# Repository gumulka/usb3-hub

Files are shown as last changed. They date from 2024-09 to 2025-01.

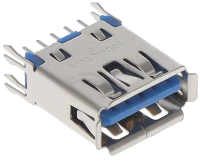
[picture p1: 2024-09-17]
kicad/images/GSB312137CHR.png

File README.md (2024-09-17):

# USB3 Hub

My very own USB3 Hub with these features:

* Power to all ports controllable via USB
* Power to all ports controllable via switch
* Current measurement on half the ports
* Current readout either via display or USB

## WIP

This is very much work in progress. I have not yet finished routing
and there is no software whatsoever for the PCB, but I'm working on it.

## Schematics

Can be found on the [here](https://gumulka.github.io/usb3-hub/usb3_hub_sch.pdf)

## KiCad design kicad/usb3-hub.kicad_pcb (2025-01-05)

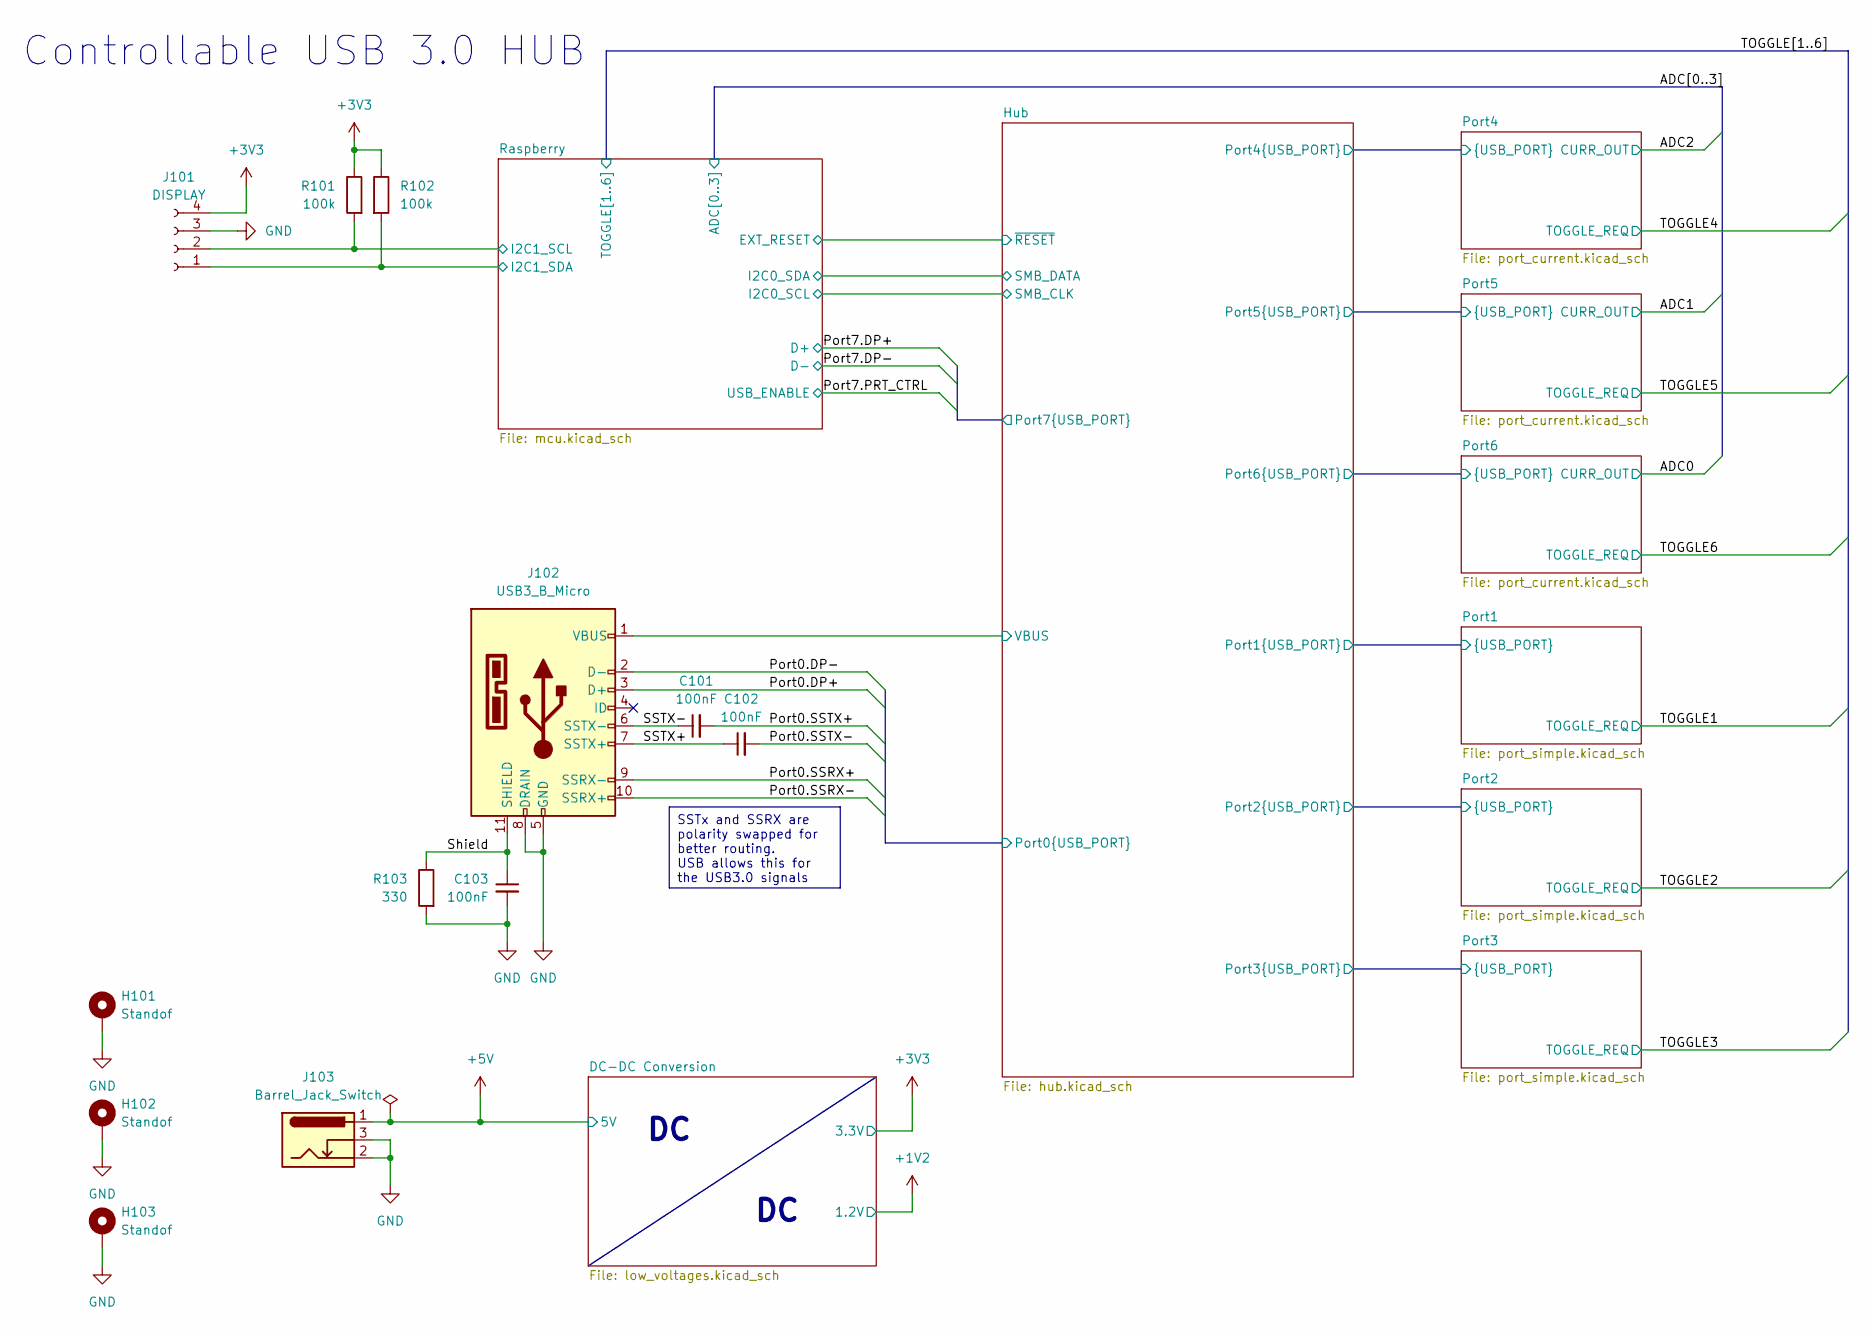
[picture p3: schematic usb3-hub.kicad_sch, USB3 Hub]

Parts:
C101, C102, C103: 100nF; C_0402_1005Metric
H101, H102, H103: Standof; MountingHole_3.2mm_M3_DIN965_Pad_TopOnly
J101: DISPLAY; PinSocket_1x04_P2.54mm_Vertical
J102: USB3_B_Micro; AMPHENOL_GSB443133HR
J103: Barrel_Jack_Switch; BarrelJack_Wuerth_6941xx301002; MPN 694106301002
R101, R102: 100k; R_0603_1608Metric
R103: 330; R_0603_1608Metric

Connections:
+3V3: J101.4, R101.1, R102.1; also elsewhere on the board
+5V: J103.1; also elsewhere on the board
/Hub/Port0.DP+: J102.3 (D+); also elsewhere on the board
/Hub/Port0.DP-: J102.2 (D-); also elsewhere on the board
/Hub/Port0.SSRX+: J102.9 (SSRX-); also elsewhere on the board
/Hub/Port0.SSRX-: J102.10 (SSRX+); also elsewhere on the board
/Hub/Port0.SSTX+: C101.2; also elsewhere on the board
/Hub/Port0.SSTX-: C102.2; also elsewhere on the board
/Hub/VBUS: J102.1 (VBUS); also elsewhere on the board
/Raspberry/I2C1_SCL: J101.2, R101.2; also elsewhere on the board
/Raspberry/I2C1_SDA: J101.1, R102.2; also elsewhere on the board
/SSTX+: C102.1, J102.7 (SSTX+)
/SSTX-: C101.1, J102.6 (SSTX-)
/Shield: C103.1, J102.11 (SHIELD), R103.1
GND: C103.2, H101.1, H102.1, H103.1, J101.3, J102.5 (GND), J102.8 (DRAIN), J103.2, J103.3, R103.2; also elsewhere on the board

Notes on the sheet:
SSTx and SSRX are polarity swapped for better routing. USB allows this for the USB3.0 signals
Controllable USB 3.0 HUB

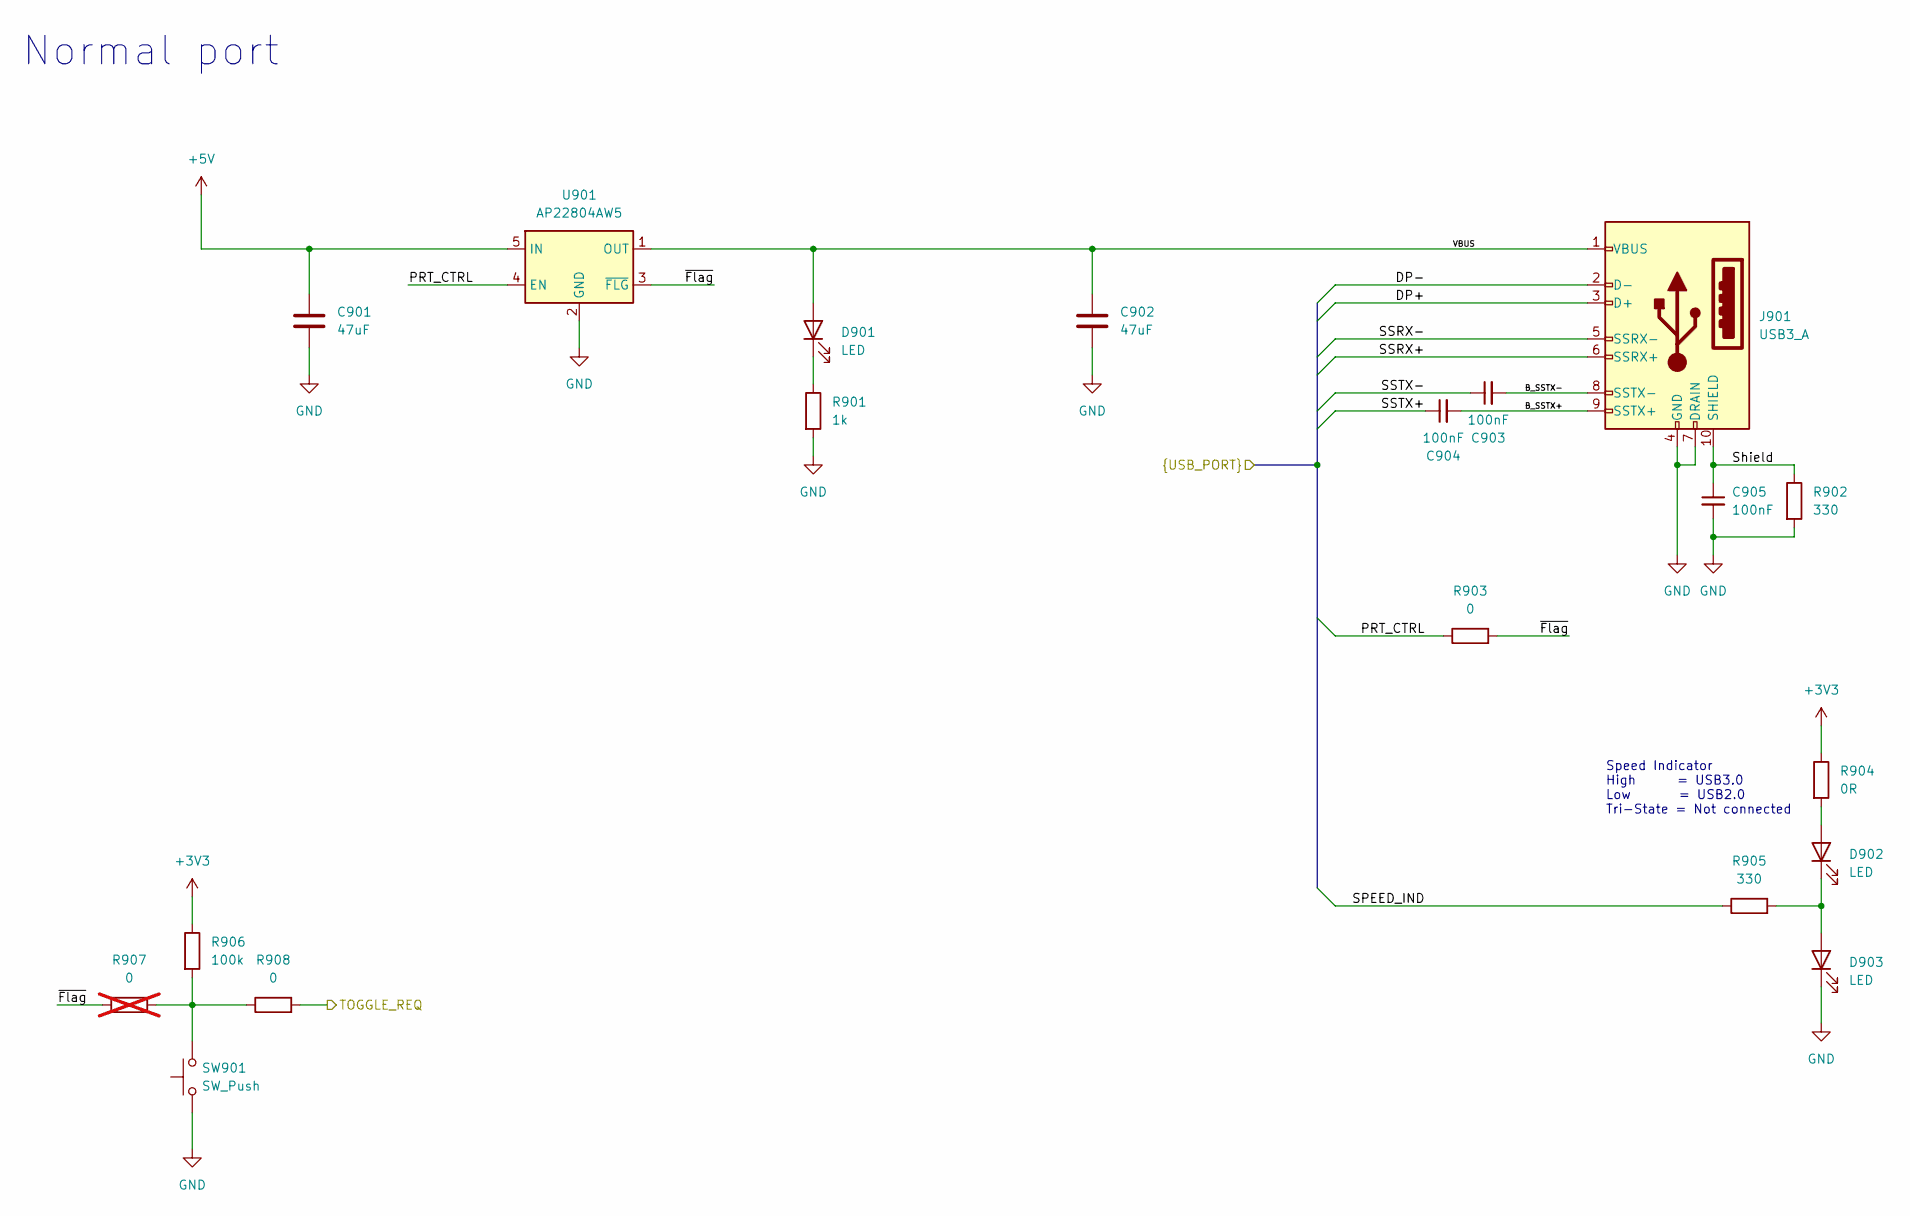
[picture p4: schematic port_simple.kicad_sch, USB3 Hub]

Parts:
C901, C902: 47uF; C_1210_3225Metric
C903, C904, C905: 100nF; C_0402_1005Metric
D901, D902, D903: LED; LED_0603_1608Metric
J901: USB3_A; AMPHENOL_GSB312137CHR
R901: 1k; R_0603_1608Metric
R902, R905: 330; R_0603_1608Metric
R903, R908: 0; R_0603_1608Metric
R904: 0R; R_0603_1608Metric
R906: 100k; R_0603_1608Metric
R907: 0; R_0603_1608Metric; not fitted
SW901: SW_Push; SW_SPST_TL3342
U901: AP22804AW5; SOT-23-5

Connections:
+3V3: R904.1, R906.1; also elsewhere on the board
+5V: C901.1, U901.5 (IN); also elsewhere on the board
/Hub/Port2.DP+: J901.3 (D+); also elsewhere on the board
/Hub/Port2.DP-: J901.2 (D-); also elsewhere on the board
/Hub/Port2.PRT_CTRL: R903.1, U901.4 (EN); also elsewhere on the board
/Hub/Port2.SPEED_IND: R905.1; also elsewhere on the board
/Hub/Port2.SSRX+: J901.6 (SSRX+); also elsewhere on the board
/Hub/Port2.SSRX-: J901.5 (SSRX-); also elsewhere on the board
/Hub/Port2.SSTX+: C904.1; also elsewhere on the board
/Hub/Port2.SSTX-: C903.1; also elsewhere on the board
/Port2/B_SSTX+: C904.2, J901.9 (SSTX+)
/Port2/B_SSTX-: C903.2, J901.8 (SSTX-)
/Port2/Shield: C905.1, J901.10 (SHIELD), R902.1
/Port2/VBUS: C902.1, D901.2 (A), J901.1 (VBUS), U901.1 (OUT)
/Port2/~Flag: R903.2, R907.1, U901.3 (~FLG)
/TOGGLE2: R908.2; also elsewhere on the board
GND: C901.2, C902.2, C905.2, D903.1 (K), J901.4 (GND), J901.7 (DRAIN), R901.2, R902.2, SW901.1, U901.2 (GND); also elsewhere on the board
unnamed: D901.1 (K), R901.1
unnamed: D902.2 (A), R904.2
unnamed: D902.1 (K), D903.2 (A), R905.2
unnamed: R906.2, R907.2, R908.1, SW901.2

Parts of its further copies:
C801, C802, C1001, C1002: 47uF; C_1210_3225Metric
C803, C804, C805, C1003, C1004, C1005: 100nF; C_0402_1005Metric
D801, D802, D803, D1001, D1002, D1003: LED; LED_0603_1608Metric
J801, J1001: USB3_A; AMPHENOL_GSB312137CHR
R801, R1001: 1k; R_0603_1608Metric
R802, R805, R1002, R1005: 330; R_0603_1608Metric
R803, R808, R1003, R1008: 0; R_0603_1608Metric
R804, R1004: 0R; R_0603_1608Metric
R806, R1006: 100k; R_0603_1608Metric
R807, R1007: 0; R_0603_1608Metric; not fitted
SW801, SW1001: SW_Push; SW_SPST_TL3342
U801, U1001: AP22804AW5; SOT-23-5

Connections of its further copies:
+3V3: R804.1, R806.1, R1004.1, R1006.1; also elsewhere on the board
+5V: C801.1, C1001.1, U801.5 (IN), U1001.5 (IN); also elsewhere on the board
/Hub/Port1.DP+: J801.3 (D+); also elsewhere on the board
/Hub/Port1.DP-: J801.2 (D-); also elsewhere on the board
/Hub/Port1.PRT_CTRL: R803.1, U801.4 (EN); also elsewhere on the board
/Hub/Port1.SPEED_IND: R805.1; also elsewhere on the board
/Hub/Port1.SSRX+: J801.6 (SSRX+); also elsewhere on the board
/Hub/Port1.SSRX-: J801.5 (SSRX-); also elsewhere on the board
/Hub/Port1.SSTX+: C804.1; also elsewhere on the board
/Hub/Port1.SSTX-: C803.1; also elsewhere on the board
/Hub/Port3.DP+: J1001.3 (D+); also elsewhere on the board
/Hub/Port3.DP-: J1001.2 (D-); also elsewhere on the board
/Hub/Port3.PRT_CTRL: R1003.1, U1001.4 (EN); also elsewhere on the board
/Hub/Port3.SPEED_IND: R1005.1; also elsewhere on the board
/Hub/Port3.SSRX+: J1001.6 (SSRX+); also elsewhere on the board
/Hub/Port3.SSRX-: J1001.5 (SSRX-); also elsewhere on the board
/Hub/Port3.SSTX+: C1004.1; also elsewhere on the board
/Hub/Port3.SSTX-: C1003.1; also elsewhere on the board
/Port1/B_SSTX+: C804.2, J801.9 (SSTX+)
/Port1/B_SSTX-: C803.2, J801.8 (SSTX-)
/Port1/Shield: C805.1, J801.10 (SHIELD), R802.1
/Port1/VBUS: C802.1, D801.2 (A), J801.1 (VBUS), U801.1 (OUT)
/Port1/~Flag: R803.2, R807.1, U801.3 (~FLG)
/Port3/B_SSTX+: C1004.2, J1001.9 (SSTX+)
/Port3/B_SSTX-: C1003.2, J1001.8 (SSTX-)
/Port3/Shield: C1005.1, J1001.10 (SHIELD), R1002.1
/Port3/VBUS: C1002.1, D1001.2 (A), J1001.1 (VBUS), U1001.1 (OUT)
/Port3/~Flag: R1003.2, R1007.1, U1001.3 (~FLG)
/TOGGLE1: R808.2; also elsewhere on the board
/TOGGLE3: R1008.2; also elsewhere on the board
GND: C801.2, C802.2, C805.2, C1001.2, C1002.2, C1005.2, D803.1 (K), D1003.1 (K), J801.4 (GND), J801.7 (DRAIN), J1001.4 (GND), J1001.7 (DRAIN), R801.2, R802.2, R1001.2, R1002.2, SW801.1, SW1001.1, U801.2 (GND), U1001.2 (GND); also elsewhere on the board
unnamed: D801.1 (K), R801.1
unnamed: D802.2 (A), R804.2
unnamed: D802.1 (K), D803.2 (A), R805.2
unnamed: D1001.1 (K), R1001.1
unnamed: D1002.2 (A), R1004.2
unnamed: D1002.1 (K), D1003.2 (A), R1005.2
unnamed: R806.2, R807.2, R808.1, SW801.2
unnamed: R1006.2, R1007.2, R1008.1, SW1001.2

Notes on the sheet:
Speed Indicator High = USB3.0 Low = USB2.0 Tri-State = Not connected
Normal port

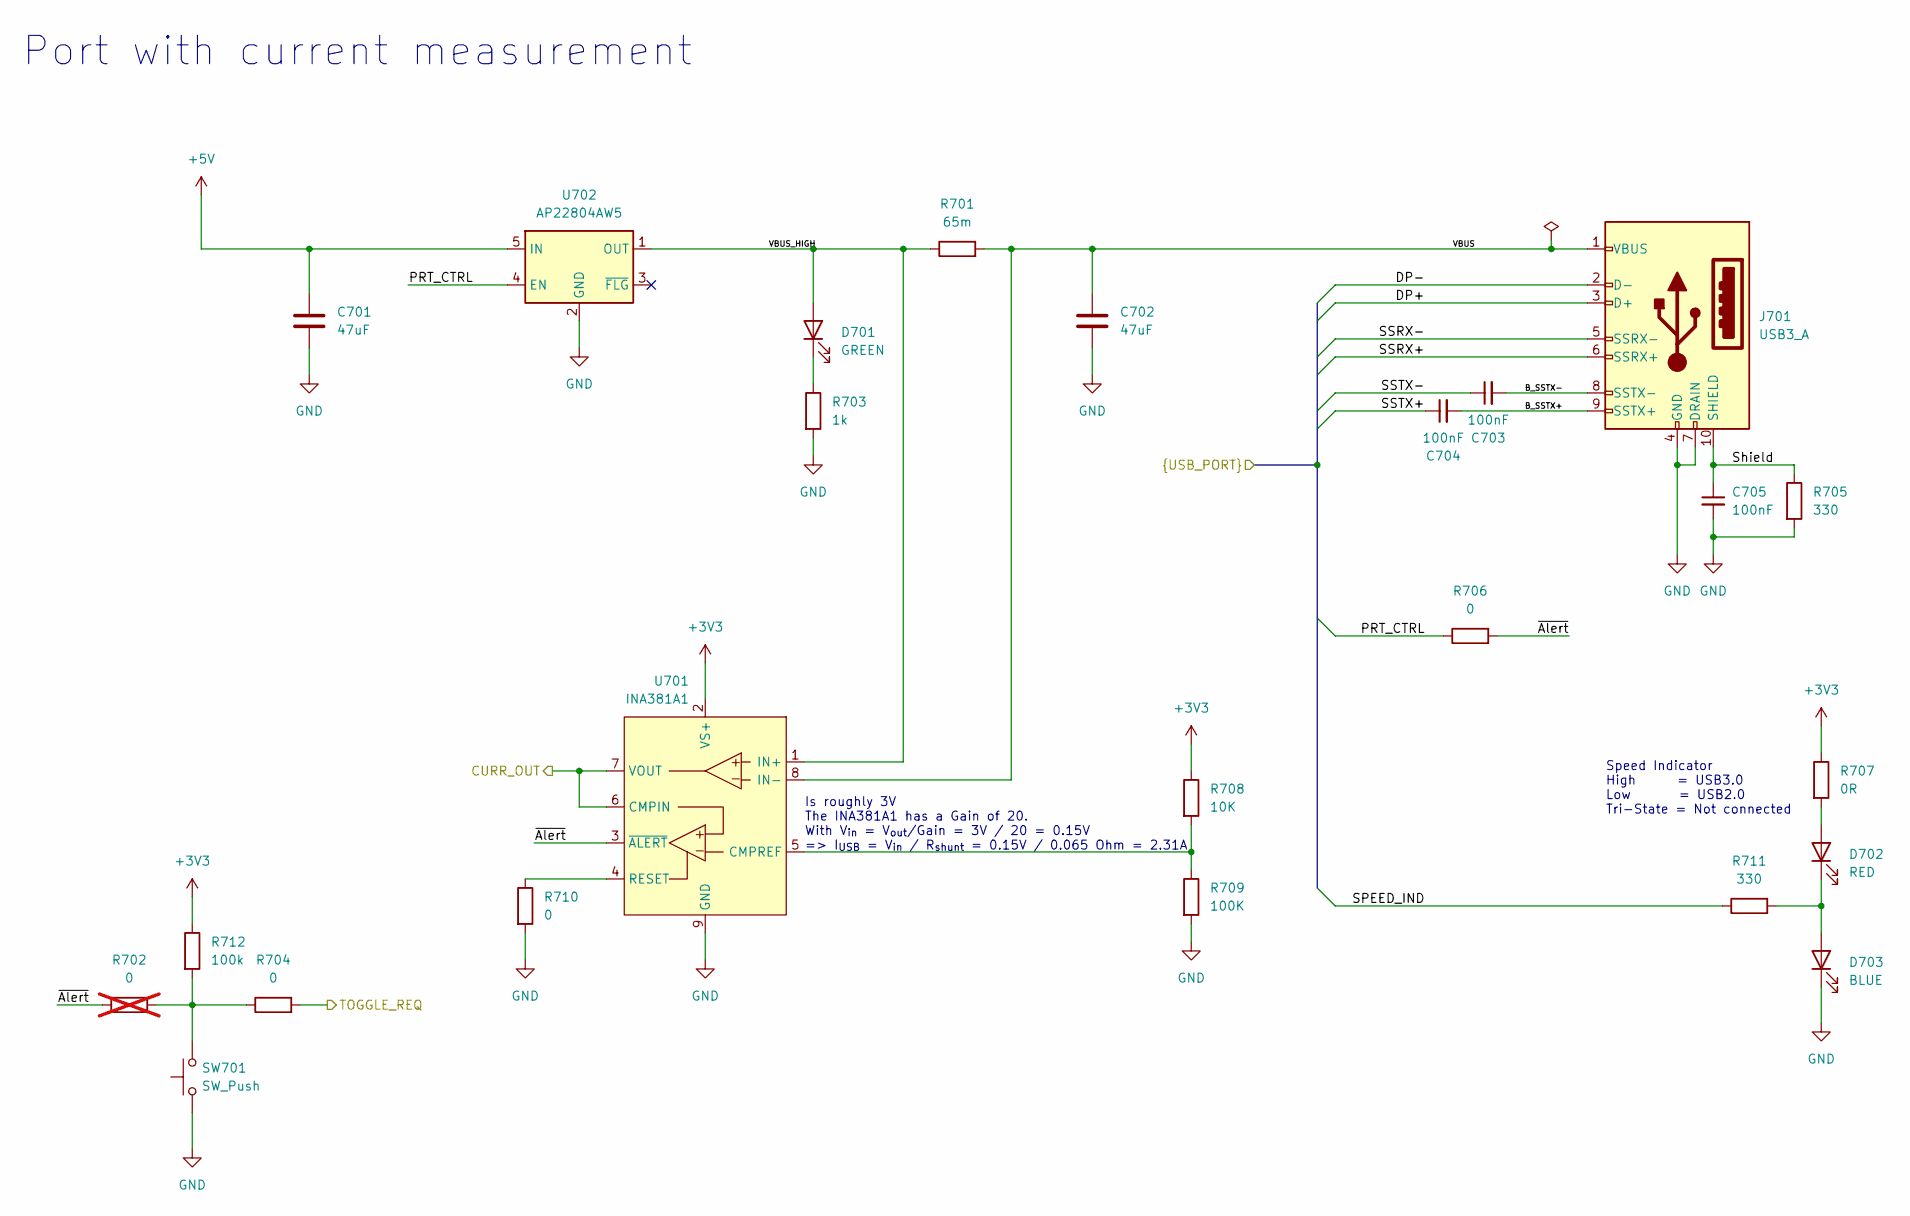
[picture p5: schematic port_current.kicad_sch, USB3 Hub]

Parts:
C701, C702: 47uF; C_1210_3225Metric
C703, C704, C705: 100nF; C_0402_1005Metric
D701: GREEN; LED_0603_1608Metric
D702: RED; LED_0603_1608Metric
D703: BLUE; LED_0603_1608Metric
J701: USB3_A; AMPHENOL_GSB312137CHR
R701: 65m; R_1206_3216Metric
R702: 0; R_0603_1608Metric; not fitted
R703: 1k; R_0603_1608Metric
R704, R706, R710: 0; R_0603_1608Metric
R705, R711: 330; R_0603_1608Metric
R707: 0R; R_0603_1608Metric
R708: 10K; R_0603_1608Metric
R709: 100K; R_0603_1608Metric
R712: 100k; R_0603_1608Metric
SW701: SW_Push; SW_SPST_TL3342
U701: INA381A1; 8-WSON_2x2mm
U702: AP22804AW5; SOT-23-5

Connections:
+3V3: R707.1, R708.1, R712.1, U701.2 (VS+); also elsewhere on the board
+5V: C701.1, U702.5 (IN); also elsewhere on the board
/ADC0: U701.6 (CMPIN), U701.7 (VOUT); also elsewhere on the board
/Hub/Port6.DP+: J701.3 (D+); also elsewhere on the board
/Hub/Port6.DP-: J701.2 (D-); also elsewhere on the board
/Hub/Port6.PRT_CTRL: R706.1, U702.4 (EN); also elsewhere on the board
/Hub/Port6.SPEED_IND: R711.1; also elsewhere on the board
/Hub/Port6.SSRX+: J701.6 (SSRX+); also elsewhere on the board
/Hub/Port6.SSRX-: J701.5 (SSRX-); also elsewhere on the board
/Hub/Port6.SSTX+: C704.1; also elsewhere on the board
/Hub/Port6.SSTX-: C703.1; also elsewhere on the board
/Port6/B_SSTX+: C704.2, J701.9 (SSTX+)
/Port6/B_SSTX-: C703.2, J701.8 (SSTX-)
/Port6/Shield: C705.1, J701.10 (SHIELD), R705.1
/Port6/VBUS: C702.1, J701.1 (VBUS), R701.2, U701.8 (IN-)
/Port6/VBUS_HIGH: D701.2 (A), R701.1, U701.1 (IN+), U702.1 (OUT)
/Port6/~Alert: R702.1, R706.2, U701.3 (~ALERT)
/TOGGLE6: R704.2; also elsewhere on the board
GND: C701.2, C702.2, C705.2, D703.1 (K), J701.4 (GND), J701.7 (DRAIN), R703.2, R705.2, R709.2, R710.2, SW701.1, U701.9 (GND), U702.2 (GND); also elsewhere on the board
unnamed: D701.1 (K), R703.1
unnamed: D702.2 (A), R707.2
unnamed: D702.1 (K), D703.2 (A), R711.2
unnamed: R702.2, R704.1, R712.2, SW701.2
unnamed: R708.2, R709.1, U701.5 (CMPREF)
unnamed: R710.1, U701.4 (RESET)

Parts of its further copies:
C501, C502, C601, C602: 47uF; C_1210_3225Metric
C503, C504, C505, C603, C604, C605: 100nF; C_0402_1005Metric
J501, J601: USB3_A; AMPHENOL_GSB312137CHR
R501, R601: 65m; R_1206_3216Metric
R502, R602: 0; R_0603_1608Metric; not fitted
R503, R603: 1k; R_0603_1608Metric
R504, R506, R510, R604, R606, R610: 0; R_0603_1608Metric
R505, R511, R605, R611: 330; R_0603_1608Metric
R507, R607: 0R; R_0603_1608Metric
R508, R608: 10K; R_0603_1608Metric
R509, R609: 100K; R_0603_1608Metric
R512, R612: 100k; R_0603_1608Metric
SW501, SW601: SW_Push; SW_SPST_TL3342
U501, U601: INA381A1; 8-WSON_2x2mm
U502, U602: AP22804AW5; SOT-23-5

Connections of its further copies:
+3V3: R507.1, R508.1, R512.1, R607.1, R608.1, R612.1, U501.2 (VS+), U601.2 (VS+); also elsewhere on the board
+5V: C501.1, C601.1, U502.5 (IN), U602.5 (IN); also elsewhere on the board
/ADC1: U601.6 (CMPIN), U601.7 (VOUT); also elsewhere on the board
/ADC2: U501.6 (CMPIN), U501.7 (VOUT); also elsewhere on the board
/Hub/Port4.DP+: J501.3 (D+); also elsewhere on the board
/Hub/Port4.DP-: J501.2 (D-); also elsewhere on the board
/Hub/Port4.PRT_CTRL: R506.1, U502.4 (EN); also elsewhere on the board
/Hub/Port4.SPEED_IND: R511.1; also elsewhere on the board
/Hub/Port4.SSRX+: J501.6 (SSRX+); also elsewhere on the board
/Hub/Port4.SSRX-: J501.5 (SSRX-); also elsewhere on the board
/Hub/Port4.SSTX+: C504.1; also elsewhere on the board
/Hub/Port4.SSTX-: C503.1; also elsewhere on the board
/Hub/Port5.DP+: J601.3 (D+); also elsewhere on the board
/Hub/Port5.DP-: J601.2 (D-); also elsewhere on the board
/Hub/Port5.PRT_CTRL: R606.1, U602.4 (EN); also elsewhere on the board
/Hub/Port5.SPEED_IND: R611.1; also elsewhere on the board
/Hub/Port5.SSRX+: J601.6 (SSRX+); also elsewhere on the board
/Hub/Port5.SSRX-: J601.5 (SSRX-); also elsewhere on the board
/Hub/Port5.SSTX+: C604.1; also elsewhere on the board
/Hub/Port5.SSTX-: C603.1; also elsewhere on the board
/Port4/B_SSTX+: C504.2, J501.9 (SSTX+)
/Port4/B_SSTX-: C503.2, J501.8 (SSTX-)
/Port4/Shield: C505.1, J501.10 (SHIELD), R505.1
/Port4/VBUS: C502.1, J501.1 (VBUS), R501.2, U501.8 (IN-)
/Port4/VBUS_HIGH: R501.1, U501.1 (IN+), U502.1 (OUT); also elsewhere on the board
/Port4/~Alert: R502.1, R506.2, U501.3 (~ALERT)
/Port5/B_SSTX+: C604.2, J601.9 (SSTX+)
/Port5/B_SSTX-: C603.2, J601.8 (SSTX-)
/Port5/Shield: C605.1, J601.10 (SHIELD), R605.1
/Port5/VBUS: C602.1, J601.1 (VBUS), R601.2, U601.8 (IN-)
/Port5/VBUS_HIGH: R601.1, U601.1 (IN+), U602.1 (OUT); also elsewhere on the board
/Port5/~Alert: R602.1, R606.2, U601.3 (~ALERT)
/TOGGLE4: R504.2; also elsewhere on the board
/TOGGLE5: R604.2; also elsewhere on the board
GND: C501.2, C502.2, C505.2, C601.2, C602.2, C605.2, J501.4 (GND), J501.7 (DRAIN), J601.4 (GND), J601.7 (DRAIN), R503.2, R505.2, R509.2, R510.2, R603.2, R605.2, R609.2, R610.2, SW501.1, SW601.1, U501.9 (GND), U502.2 (GND), U601.9 (GND), U602.2 (GND); also elsewhere on the board
unnamed 140: R503.1; also elsewhere on the board
unnamed 141: R507.2; also elsewhere on the board
unnamed 142: R511.2; also elsewhere on the board
unnamed 143: R603.1; also elsewhere on the board
unnamed 144: R607.2; also elsewhere on the board
unnamed 145: R611.2; also elsewhere on the board
unnamed: R502.2, R504.1, R512.2, SW501.2
unnamed: R602.2, R604.1, R612.2, SW601.2
unnamed: R508.2, R509.1, U501.5 (CMPREF)
unnamed: R510.1, U501.4 (RESET)
unnamed: R608.2, R609.1, U601.5 (CMPREF)
unnamed: R610.1, U601.4 (RESET)

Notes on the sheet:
Port with current measurement
Is roughly 3V The INA381A1 has a Gain of 20. With V_{in} = V_{out}/Gain = 3V / 20 = 0.15V => I_{USB} = V_{in} / R_{shunt} = 0.15V / 0.065 Ohm = 2.31A
Speed Indicator High = USB3.0 Low = USB2.0 Tri-State = Not connected

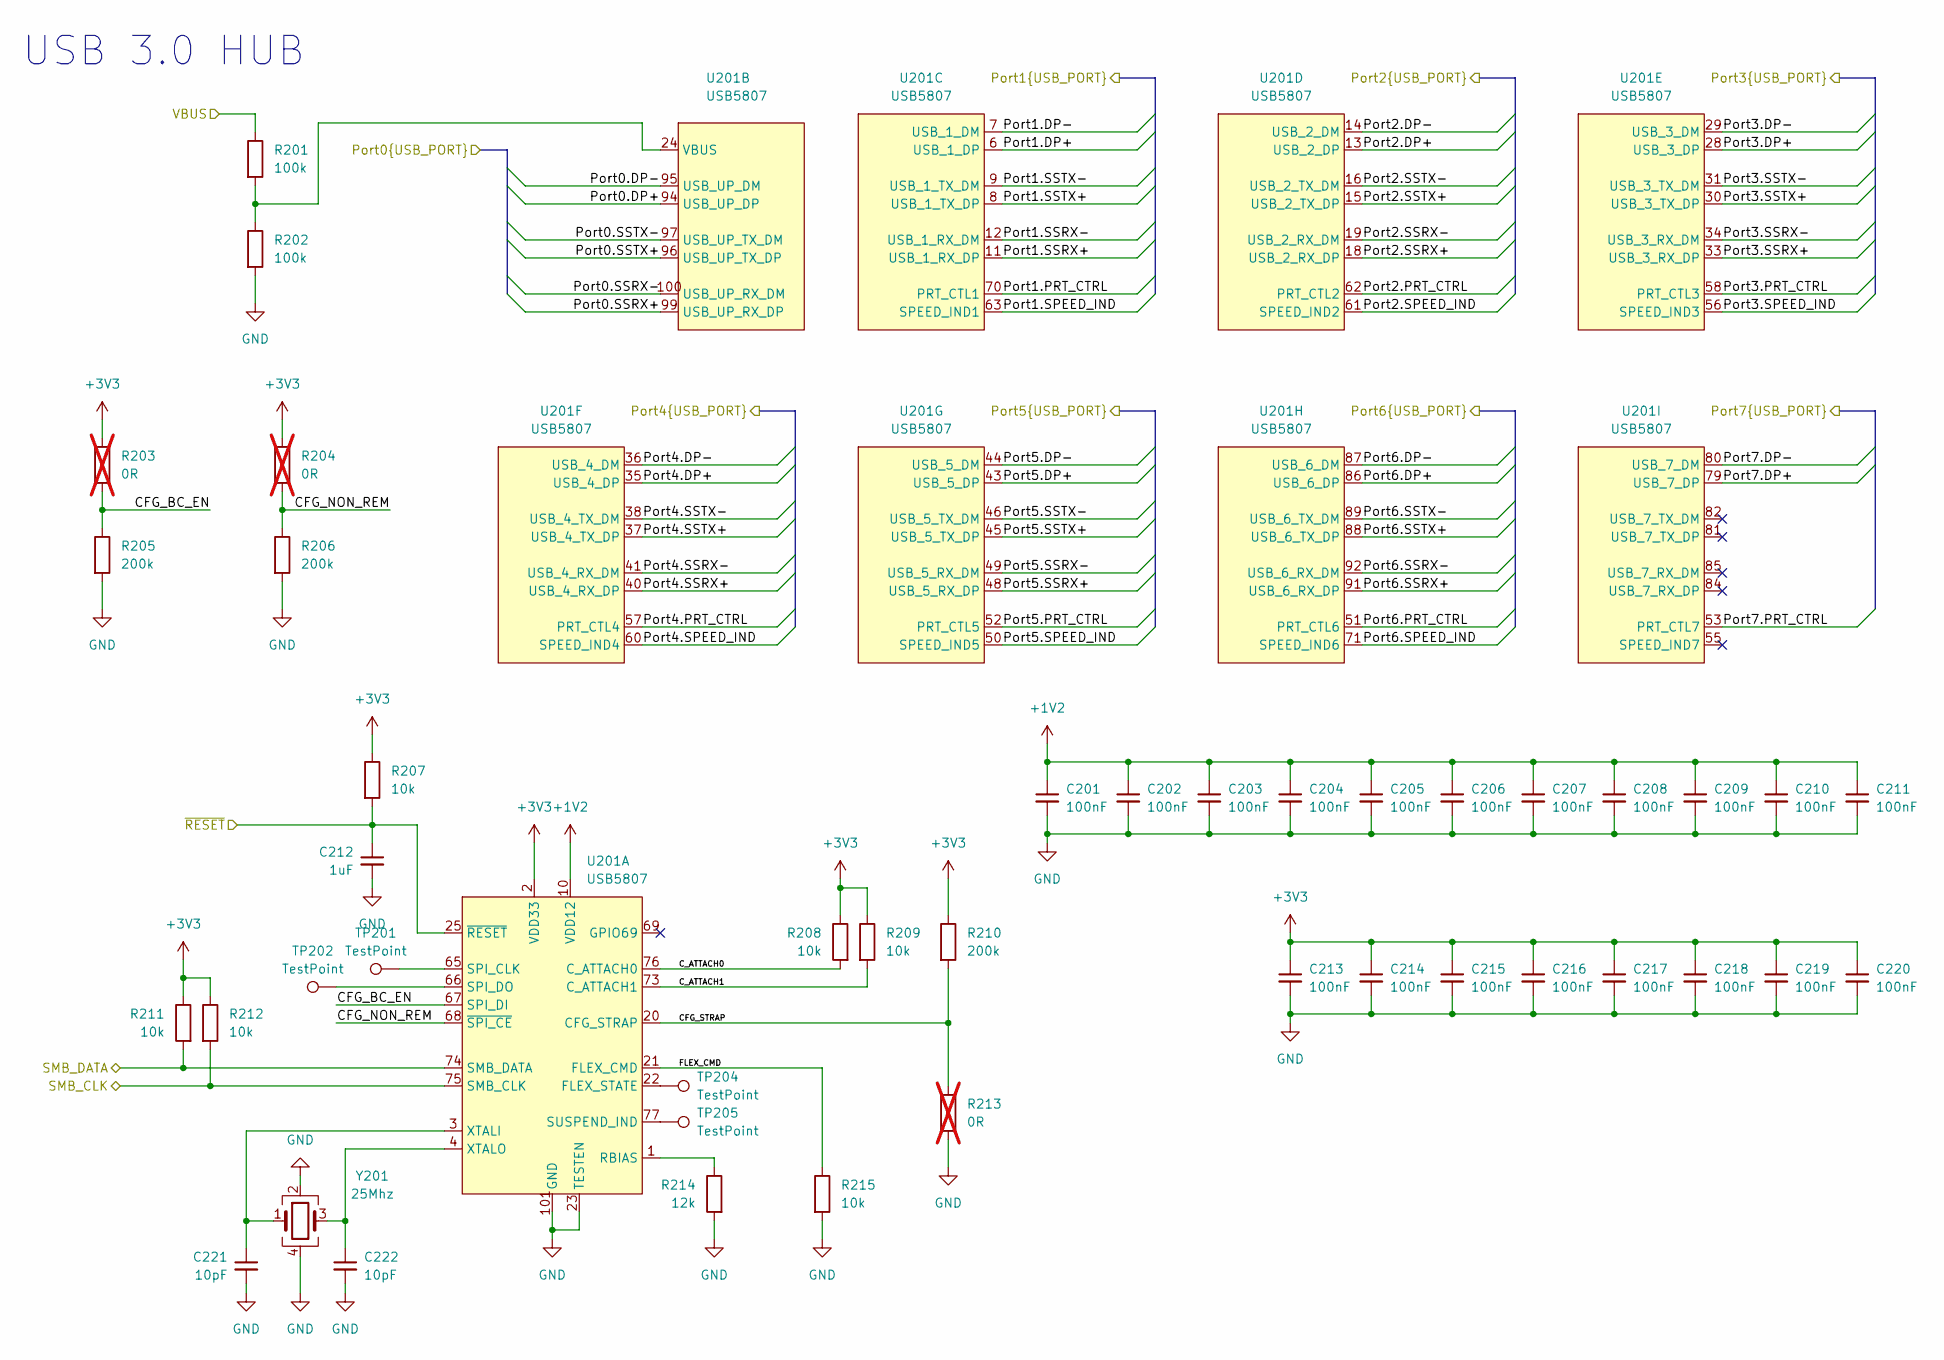
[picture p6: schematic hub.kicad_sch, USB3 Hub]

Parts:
C201, C202, C203, C204, C205, C206, C207, C208, C209, C210, C211, C213, C214, C215, C216, C217, C218, C219, C220: 100nF; C_0402_1005Metric
C212: 1uF; C_0603_1608Metric
C221, C222: 10pF; C_0402_1005Metric
R201, R202: 100k; R_0603_1608Metric
R203, R204, R213: 0R; R_0603_1608Metric; not fitted
R205, R206, R210: 200k; R_0603_1608Metric
R207, R208, R209, R211, R212, R215: 10k; R_0603_1608Metric
R214: 12k; R_0603_1608Metric
TP201, TP202, TP204, TP205: TestPoint; TestPoint_Pad_D1.0mm
U201: USB5807; 100-VQFN
Y201: 25Mhz; Crystal_SMD_Abracon_ABM8G-4Pin_3.2x2.5mm; PartNo ABM8G-25.000MHZ-B4Y-T

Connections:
+1V2: C201.1, C202.1, C203.1, C204.1, C205.1, C206.1, C207.1, C208.1, C209.1, C210.1, C211.1, U201.10 (VDD12), U201.17 (VDD12), U201.26 (VDD12), U201.32 (VDD12), U201.39 (VDD12), U201.47 (VDD12), U201.59 (VDD12), U201.78 (VDD12), U201.83 (VDD12), U201.90 (VDD12), U201.98 (VDD12); also elsewhere on the board
+3V3: C213.1, C214.1, C215.1, C216.1, C217.1, C218.1, C219.1, C220.1, R203.1, R204.1, R207.1, R208.1, R209.1, R210.1, R211.1, R212.1, U201.2 (VDD33), U201.5 (VDD33), U201.27 (VDD33), U201.42 (VDD33), U201.54 (VDD33), U201.64 (VDD33), U201.72 (VDD33), U201.93 (VDD33); also elsewhere on the board
/Hub/CFG_BC_EN: R203.2, R205.1, U201.67 (SPI_DI)
/Hub/CFG_NON_REM: R204.2, R206.1, U201.68 (~SPI_CE)
/Hub/CFG_STRAP: R210.2, R213.1, U201.20 (CFG_STRAP)
/Hub/C_ATTACH0: R208.2, U201.76 (C_ATTACH0)
/Hub/C_ATTACH1: R209.2, U201.73 (C_ATTACH1)
/Hub/FLEX_CMD: R215.1, U201.21 (FLEX_CMD)
/Hub/Port0.DP+: U201.94 (USB_UP_DP); also elsewhere on the board
/Hub/Port0.DP-: U201.95 (USB_UP_DM); also elsewhere on the board
/Hub/Port0.SSRX+: U201.99 (USB_UP_RX_DP); also elsewhere on the board
/Hub/Port0.SSRX-: U201.100 (USB_UP_RX_DM); also elsewhere on the board
/Hub/Port0.SSTX+: U201.96 (USB_UP_TX_DP); also elsewhere on the board
/Hub/Port0.SSTX-: U201.97 (USB_UP_TX_DM); also elsewhere on the board
/Hub/Port1.DP+: U201.6 (USB_1_DP); also elsewhere on the board
/Hub/Port1.DP-: U201.7 (USB_1_DM); also elsewhere on the board
/Hub/Port1.PRT_CTRL: U201.70 (PRT_CTL1); also elsewhere on the board
/Hub/Port1.SPEED_IND: U201.63 (SPEED_IND1); also elsewhere on the board
/Hub/Port1.SSRX+: U201.11 (USB_1_RX_DP); also elsewhere on the board
/Hub/Port1.SSRX-: U201.12 (USB_1_RX_DM); also elsewhere on the board
/Hub/Port1.SSTX+: U201.8 (USB_1_TX_DP); also elsewhere on the board
/Hub/Port1.SSTX-: U201.9 (USB_1_TX_DM); also elsewhere on the board
/Hub/Port2.DP+: U201.13 (USB_2_DP); also elsewhere on the board
/Hub/Port2.DP-: U201.14 (USB_2_DM); also elsewhere on the board
/Hub/Port2.PRT_CTRL: U201.62 (PRT_CTL2); also elsewhere on the board
/Hub/Port2.SPEED_IND: U201.61 (SPEED_IND2); also elsewhere on the board
/Hub/Port2.SSRX+: U201.18 (USB_2_RX_DP); also elsewhere on the board
/Hub/Port2.SSRX-: U201.19 (USB_2_RX_DM); also elsewhere on the board
/Hub/Port2.SSTX+: U201.15 (USB_2_TX_DP); also elsewhere on the board
/Hub/Port2.SSTX-: U201.16 (USB_2_TX_DM); also elsewhere on the board
/Hub/Port3.DP+: U201.28 (USB_3_DP); also elsewhere on the board
/Hub/Port3.DP-: U201.29 (USB_3_DM); also elsewhere on the board
/Hub/Port3.PRT_CTRL: U201.58 (PRT_CTL3); also elsewhere on the board
/Hub/Port3.SPEED_IND: U201.56 (SPEED_IND3); also elsewhere on the board
/Hub/Port3.SSRX+: U201.33 (USB_3_RX_DP); also elsewhere on the board
/Hub/Port3.SSRX-: U201.34 (USB_3_RX_DM); also elsewhere on the board
/Hub/Port3.SSTX+: U201.30 (USB_3_TX_DP); also elsewhere on the board
/Hub/Port3.SSTX-: U201.31 (USB_3_TX_DM); also elsewhere on the board
/Hub/Port4.DP+: U201.35 (USB_4_DP); also elsewhere on the board
/Hub/Port4.DP-: U201.36 (USB_4_DM); also elsewhere on the board
/Hub/Port4.PRT_CTRL: U201.57 (PRT_CTL4); also elsewhere on the board
/Hub/Port4.SPEED_IND: U201.60 (SPEED_IND4); also elsewhere on the board
/Hub/Port4.SSRX+: U201.40 (USB_4_RX_DP); also elsewhere on the board
/Hub/Port4.SSRX-: U201.41 (USB_4_RX_DM); also elsewhere on the board
/Hub/Port4.SSTX+: U201.37 (USB_4_TX_DP); also elsewhere on the board
/Hub/Port4.SSTX-: U201.38 (USB_4_TX_DM); also elsewhere on the board
/Hub/Port5.DP+: U201.43 (USB_5_DP); also elsewhere on the board
/Hub/Port5.DP-: U201.44 (USB_5_DM); also elsewhere on the board
/Hub/Port5.PRT_CTRL: U201.52 (PRT_CTL5); also elsewhere on the board
/Hub/Port5.SPEED_IND: U201.50 (SPEED_IND5); also elsewhere on the board
/Hub/Port5.SSRX+: U201.48 (USB_5_RX_DP); also elsewhere on the board
/Hub/Port5.SSRX-: U201.49 (USB_5_RX_DM); also elsewhere on the board
/Hub/Port5.SSTX+: U201.45 (USB_5_TX_DP); also elsewhere on the board
/Hub/Port5.SSTX-: U201.46 (USB_5_TX_DM); also elsewhere on the board
/Hub/Port6.DP+: U201.86 (USB_6_DP); also elsewhere on the board
/Hub/Port6.DP-: U201.87 (USB_6_DM); also elsewhere on the board
/Hub/Port6.PRT_CTRL: U201.51 (PRT_CTL6); also elsewhere on the board
/Hub/Port6.SPEED_IND: U201.71 (SPEED_IND6); also elsewhere on the board
/Hub/Port6.SSRX+: U201.91 (USB_6_RX_DP); also elsewhere on the board
/Hub/Port6.SSRX-: U201.92 (USB_6_RX_DM); also elsewhere on the board
/Hub/Port6.SSTX+: U201.88 (USB_6_TX_DP); also elsewhere on the board
/Hub/Port6.SSTX-: U201.89 (USB_6_TX_DM); also elsewhere on the board
/Hub/Port7.DP+: U201.79 (USB_7_DP); also elsewhere on the board
/Hub/Port7.DP-: U201.80 (USB_7_DM); also elsewhere on the board
/Hub/Port7.PRT_CTRL: U201.53 (PRT_CTL7); also elsewhere on the board
/Hub/SMB_CLK: R212.2, U201.75 (SMB_CLK); also elsewhere on the board
/Hub/SMB_DATA: R211.2, U201.74 (SMB_DATA); also elsewhere on the board
/Hub/VBUS: R201.1; also elsewhere on the board
/Hub/~RESET: C212.1, R207.2, U201.25 (~RESET); also elsewhere on the board
GND: C201.2, C202.2, C203.2, C204.2, C205.2, C206.2, C207.2, C208.2, C209.2, C210.2, C211.2, C212.2, C213.2, C214.2, C215.2, C216.2, C217.2, C218.2, C219.2, C220.2, C221.2, C222.2, R202.2, R205.2, R206.2, R213.2, R214.2, R215.2, U201.23 (TESTEN), U201.101 (GND), Y201.2, Y201.4; also elsewhere on the board
unnamed: TP204.1, U201.22 (FLEX_STATE)
unnamed: R214.1, U201.1 (RBIAS)
unnamed: TP201.1, U201.65 (SPI_CLK)
unnamed: TP202.1, U201.66 (SPI_DO)
unnamed: TP205.1, U201.77 (SUSPEND_IND)
unnamed: C221.1, U201.3 (XTALI), Y201.1
unnamed: C222.1, U201.4 (XTALO), Y201.3
unnamed: R201.2, R202.1, U201.24 (VBUS)

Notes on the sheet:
USB 3.0 HUB

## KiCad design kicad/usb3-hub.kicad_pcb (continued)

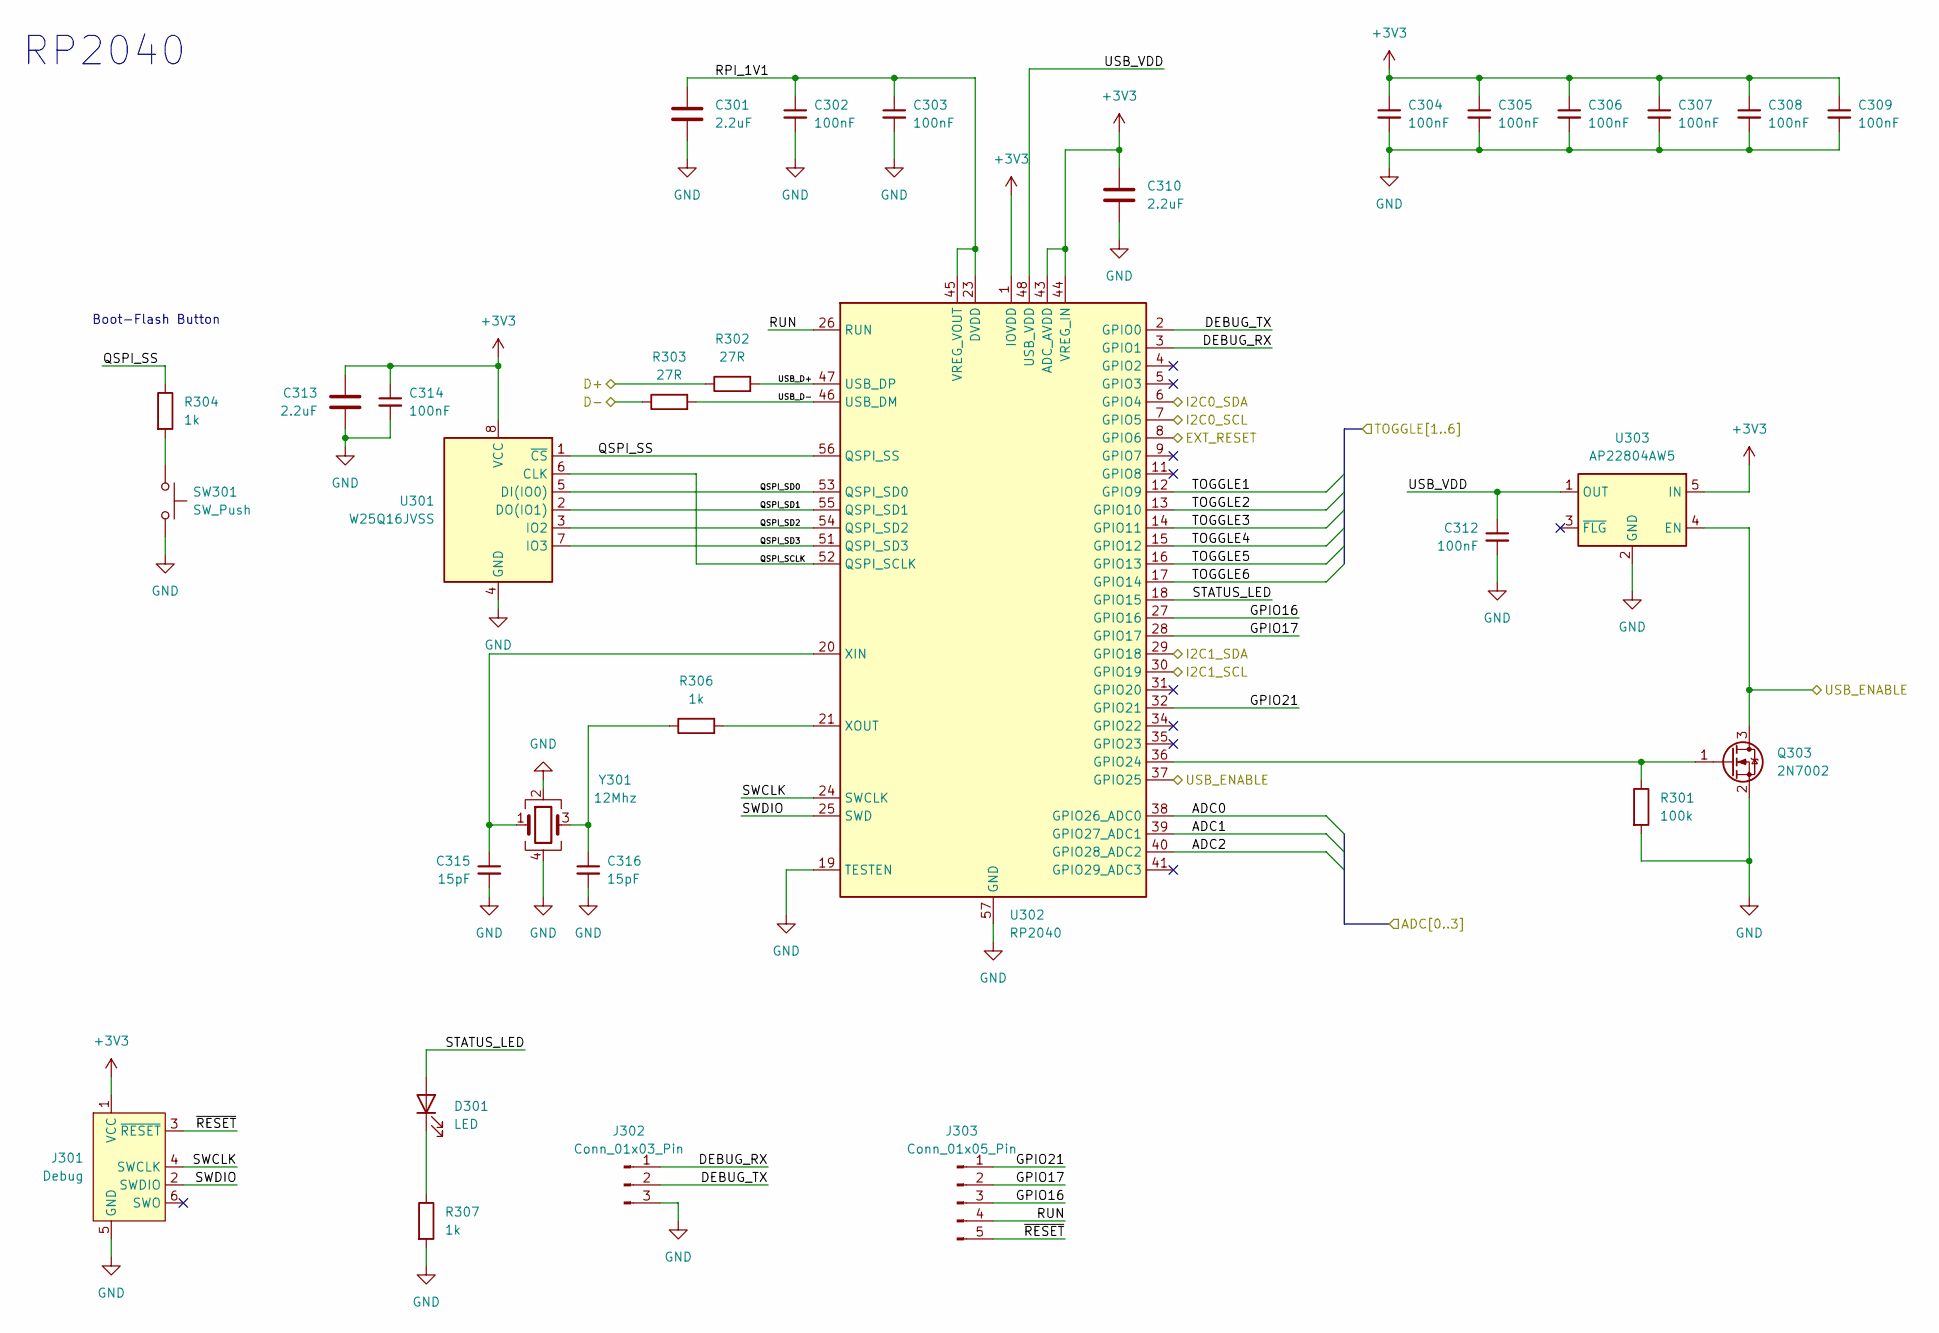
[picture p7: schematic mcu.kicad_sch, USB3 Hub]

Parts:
C301, C310, C313: 2.2uF; C_0603_1608Metric
C302, C303, C304, C305, C306, C307, C308, C309, C312, C314: 100nF; C_0402_1005Metric
C315, C316: 15pF; C_0402_1005Metric
D301: LED; LED_0603_1608Metric
J301: Debug; Tag-Connect_TC2030-IDC-NL_2x03_P1.27mm_Vertical
J302: Conn_01x03_Pin; PinHeader_1x03_P2.54mm_Vertical
J303: Conn_01x05_Pin; PinSocket_1x05_P2.54mm_Vertical
Q303: 2N7002; SOT-23
R301: 100k; R_0603_1608Metric
R302, R303: 27R; R_0402_1005Metric
R304, R306, R307: 1k; R_0603_1608Metric
SW301: SW_Push; SW_SPST_TL3342
U301: W25Q16JVSS; SOIC-8_5.23x5.23mm_P1.27mm
U302: RP2040; QFN-56-1EP_7x7mm_P0.4mm_EP3.2x3.2mm
U303: AP22804AW5; SOT-23-5
Y301: 12Mhz; Crystal_SMD_3225-4Pin_3.2x2.5mm; PartNo ABM8-272-T3

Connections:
+3V3: C304.1, C305.1, C306.1, C307.1, C308.1, C309.1, C310.1, C313.1, C314.1, J301.1 (VCC), U301.8 (VCC), U302.1 (IOVDD), U302.10 (IOVDD), U302.22 (IOVDD), U302.33 (IOVDD), U302.42 (IOVDD), U302.43 (ADC_AVDD), U302.44 (VREG_IN), U302.49 (IOVDD), U303.5 (IN); also elsewhere on the board
/ADC0: U302.38 (GPIO26_ADC0); also elsewhere on the board
/ADC1: U302.39 (GPIO27_ADC1); also elsewhere on the board
/ADC2: U302.40 (GPIO28_ADC2); also elsewhere on the board
/Hub/Port7.DP+: R302.1; also elsewhere on the board
/Hub/Port7.DP-: R303.1; also elsewhere on the board
/Hub/Port7.PRT_CTRL: Q303.3 (D), U302.37 (GPIO25), U303.4 (EN); also elsewhere on the board
/Hub/SMB_CLK: U302.7 (GPIO5); also elsewhere on the board
/Hub/SMB_DATA: U302.6 (GPIO4); also elsewhere on the board
/Hub/~RESET: U302.8 (GPIO6); also elsewhere on the board
/Raspberry/DEBUG_RX: J302.1, U302.3 (GPIO1)
/Raspberry/DEBUG_TX: J302.2, U302.2 (GPIO0)
/Raspberry/GPIO16: J303.3, U302.27 (GPIO16)
/Raspberry/GPIO17: J303.2, U302.28 (GPIO17)
/Raspberry/GPIO21: J303.1, U302.32 (GPIO21)
/Raspberry/I2C1_SCL: U302.30 (GPIO19); also elsewhere on the board
/Raspberry/I2C1_SDA: U302.29 (GPIO18); also elsewhere on the board
/Raspberry/QSPI_SCLK: U301.6 (CLK), U302.52 (QSPI_SCLK)
/Raspberry/QSPI_SD0: U301.5 (DI(IO0)), U302.53 (QSPI_SD0)
/Raspberry/QSPI_SD1: U301.2 (DO(IO1)), U302.55 (QSPI_SD1)
/Raspberry/QSPI_SD2: U301.3 (IO2), U302.54 (QSPI_SD2)
/Raspberry/QSPI_SD3: U301.7 (IO3), U302.51 (QSPI_SD3)
/Raspberry/QSPI_SS: R304.1, U301.1 (~CS), U302.56 (QSPI_SS)
/Raspberry/RPI_1V1: C301.1, C302.1, C303.1, U302.23 (DVDD), U302.45 (VREG_VOUT), U302.50 (DVDD)
/Raspberry/RUN: J303.4, U302.26 (RUN)
/Raspberry/STATUS_LED: D301.2 (A), U302.18 (GPIO15)
/Raspberry/SWCLK: J301.4 (SWCLK), U302.24 (SWCLK)
/Raspberry/SWDIO: J301.2 (SWDIO), U302.25 (SWD)
/Raspberry/USB_D+: R302.2, U302.47 (USB_DP)
/Raspberry/USB_D-: R303.2, U302.46 (USB_DM)
/Raspberry/USB_VDD: C312.1, U302.48 (USB_VDD), U303.1 (OUT)
/Raspberry/~RESET: J301.3 (~RESET), J303.5
/TOGGLE1: U302.12 (GPIO9); also elsewhere on the board
/TOGGLE2: U302.13 (GPIO10); also elsewhere on the board
/TOGGLE3: U302.14 (GPIO11); also elsewhere on the board
/TOGGLE4: U302.15 (GPIO12); also elsewhere on the board
/TOGGLE5: U302.16 (GPIO13); also elsewhere on the board
/TOGGLE6: U302.17 (GPIO14); also elsewhere on the board
GND: C301.2, C302.2, C303.2, C304.2, C305.2, C306.2, C307.2, C308.2, C309.2, C310.2, C312.2, C313.2, C314.2, C315.2, C316.2, J301.5 (GND), J302.3, Q303.2 (S), R301.2, R307.2, SW301.2, U301.4 (GND), U302.19 (TESTEN), U302.57 (GND), U303.2 (GND), Y301.2, Y301.4; also elsewhere on the board
unnamed: C316.1, R306.1, Y301.3
unnamed: D301.1 (K), R307.1
unnamed: Q303.1 (G), R301.1, U302.36 (GPIO24)
unnamed: R304.2, SW301.1
unnamed: C315.1, U302.20 (XIN), Y301.1
unnamed: R306.2, U302.21 (XOUT)

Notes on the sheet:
RP2040
Boot-Flash Button

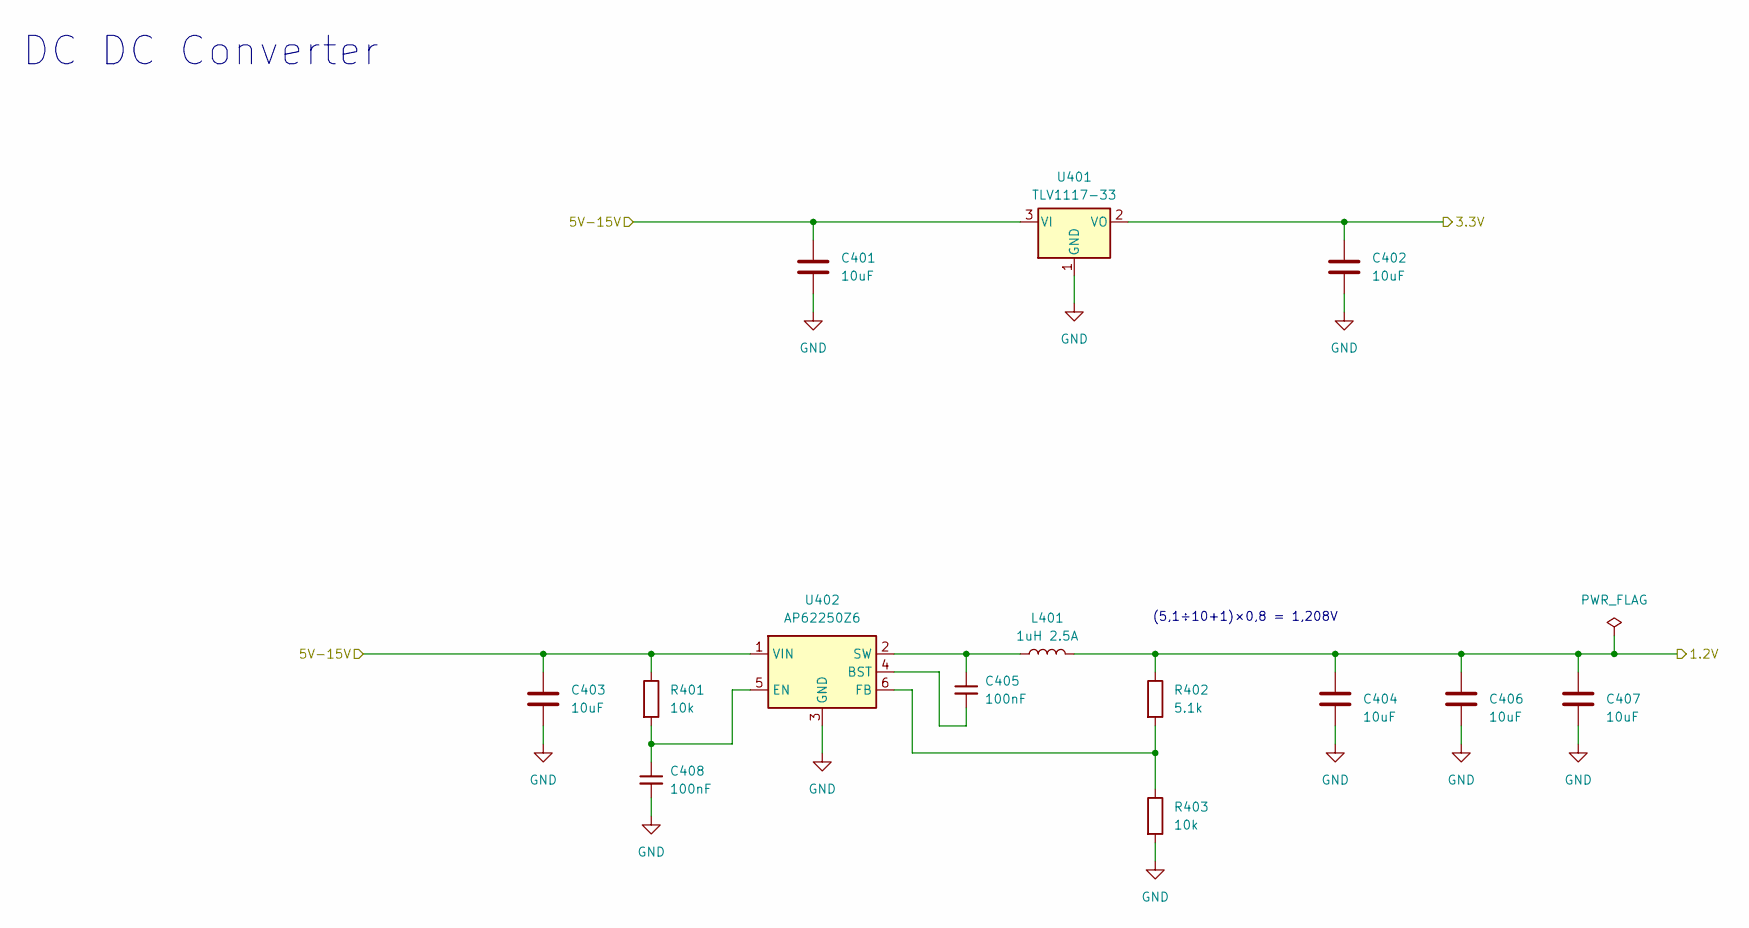
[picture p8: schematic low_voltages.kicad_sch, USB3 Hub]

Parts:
C401, C402, C403, C404, C406, C407: 10uF; C_0805_2012Metric
C405, C408: 100nF; C_0402_1005Metric
L401: 1uH 2.5A; L_Bourns-SRN4018
R401, R403: 10k; R_0603_1608Metric
R402: 5.1k; R_0603_1608Metric
U401: TLV1117-33; SOT-223-3_TabPin2
U402: AP62250Z6; SOT-563

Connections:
+1V2: C404.1, C406.1, C407.1, L401.2, R402.1; also elsewhere on the board
+3V3: C402.1, U401.2 (VO); also elsewhere on the board
+5V: C401.1, C403.1, R401.1, U401.3 (VI), U402.1 (VIN); also elsewhere on the board
GND: C401.2, C402.2, C403.2, C404.2, C406.2, C407.2, C408.2, R403.2, U401.1 (GND), U402.3 (GND); also elsewhere on the board
unnamed: C405.2, U402.4 (BST)
unnamed: C408.1, R401.2, U402.5 (EN)
unnamed: R402.2, R403.1, U402.6 (FB)
unnamed: C405.1, L401.1, U402.2 (SW)

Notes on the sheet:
DC DC Converter
(5,1÷10+1)×0,8 = 1,208V

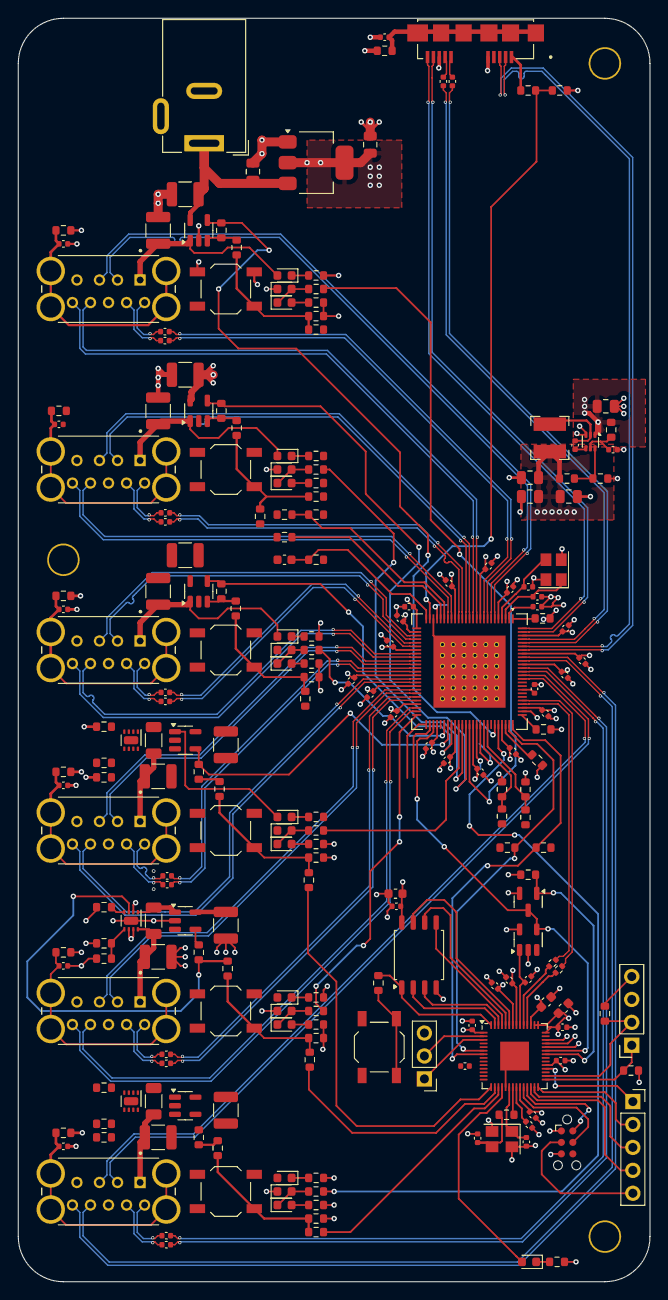
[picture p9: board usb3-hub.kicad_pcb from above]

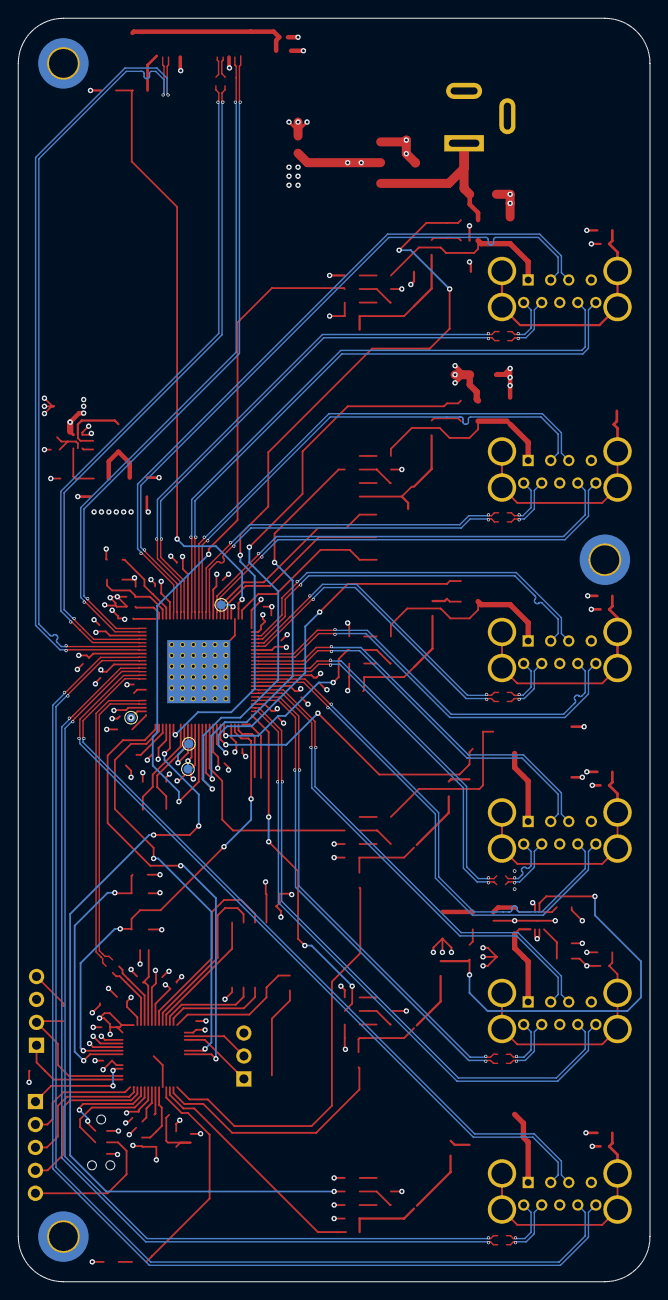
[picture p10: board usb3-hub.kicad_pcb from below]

Board: 6 copper layers, 70.0 x 140.0 mm, 229 parts (7 on the bottom side), 186 nets.

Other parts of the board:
D501, D502, D503, D601, D602, D603: LED; LED_0603_1608Metric

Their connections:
/Port4/VBUS_HIGH: D501.2 (A); also elsewhere on the board
/Port5/VBUS_HIGH: D601.2 (A); also elsewhere on the board
GND: D503.1 (K), D603.1 (K); also elsewhere on the board
unnamed 140: D501.1 (K); also elsewhere on the board
unnamed 141: D502.2 (A); also elsewhere on the board
unnamed 142: D502.1 (K), D503.2 (A); also elsewhere on the board
unnamed 143: D601.1 (K); also elsewhere on the board
unnamed 144: D602.2 (A); also elsewhere on the board
unnamed 145: D602.1 (K), D603.2 (A); also elsewhere on the board

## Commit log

2024-09-17 Started with drawing a rough schematic for a hub
    Started drawing a schematic of how a USB3 hub with support for toggling
    the ports via USB-Command and Buttons could look like.
    The Idea is, that the HUB will toggle power output, but can be written
    via SMBUS from the RP2040, which is also connected via a port to the
    USB-Hub, to give feedback about power drawn from the other ports to the
    system for current consumption montoring.
    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
    [hub.kicad_sch, low_voltages.kicad_sch, mcu.kicad_sch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]
2024-09-17 First rough placement
    Just to get an idea on how it might look like
    Added trace widts for Differential pairs
    Using 6 layers, because it makes power management easier.
    Rather large PCB, but better to big, then to small.
    [hub.kicad_sch, low_voltages.kicad_sch, mcu.kicad_sch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]
2024-09-17 Added first fanout for usb5807
    Needs a lot more work, but it is a start, that allows me to concentrate
    on the routing of USB signals and have the capacitors relatively close
    to the hub controller.
    [hub.kicad_sch, mcu.kicad_sch, port_current.kicad_sch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]
2024-09-17 Some more routing
    Not done, but done some more. Nothing is final, just to get a
    better feeling of what could be done.
    [mcu.kicad_sch, usb3-hub.kicad_pcb, usb3-hub.kicad_sch]
2024-09-17 Add README with link to the schematics
    Schematics are automatically generated via actions and deployed using
    pages.
    [hub.kicad_sch]
2024-09-17 Add check for DRC
    Only checking errors at the moment, as the board is not ready yet
    Moved unconnected Items to severity warning.
    [mcu.kicad_sch, usb3-hub.kicad_pcb]
2024-09-17 Some more routing
    rearranged the LED's
    Exchanged the testpoints with a 1x5 connector.
    [mcu.kicad_sch, usb3-hub.kicad_pcb, usb3-hub.kicad_sch]
2024-09-17 Replace 1.2V LDO with switching regulator
    It just feels more reliable.
    Also added 0R resistors between switch and alert signal. My hope is
    that I can tell the switch to diable the port by pulling the
    overcurrent low.
    [low_voltages.kicad_sch, port_current.kicad_sch, port_simple.kicad_sch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]
2024-09-18 Add schematics for USB5807 evaluation board
    A lot of information is taken from this schematic for the USB-Hub to
    know how it works and what should or could be there on the pins.
2025-01-05 Some more routing
    [low_voltages.kicad_sch, port_current.kicad_sch, port_simple.kicad_sch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]
2025-03-24 Update Pulldown resitor value
    It should not be 1:1, but 1:2 ratio per reference design
    [hub.kicad_sch]
